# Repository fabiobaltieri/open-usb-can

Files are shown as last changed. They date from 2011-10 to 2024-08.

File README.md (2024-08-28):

Open-USB-CAN
============

This project is an USB to CANBus interface based on the ATMega32U2 and an
MCP2515 SPI CANBus controller.

The design features full electrical isolation for the CANBus interface and a
socketcan compliant Linux kernel driver.

> **Warning**
>
> This is not maintained or updated, please check out
> https://github.com/CANnectivity/ or
> https://github.com/candle-usb/candleLight_fw instead.

License
-------

This program is free software: you can redistribute it and/or modify
it under the terms of the GNU General Public License as published by
the Free Software Foundation, either version 3 of the License, or
(at your option) any later version.

Contents
--------

    COPYING        text version of the GPL
    README         this file
    hardware/      source directory for the hardware design files
    firmware/      source directory for the firmware source code
    kernel-module/ source directory for the kernel driver source code

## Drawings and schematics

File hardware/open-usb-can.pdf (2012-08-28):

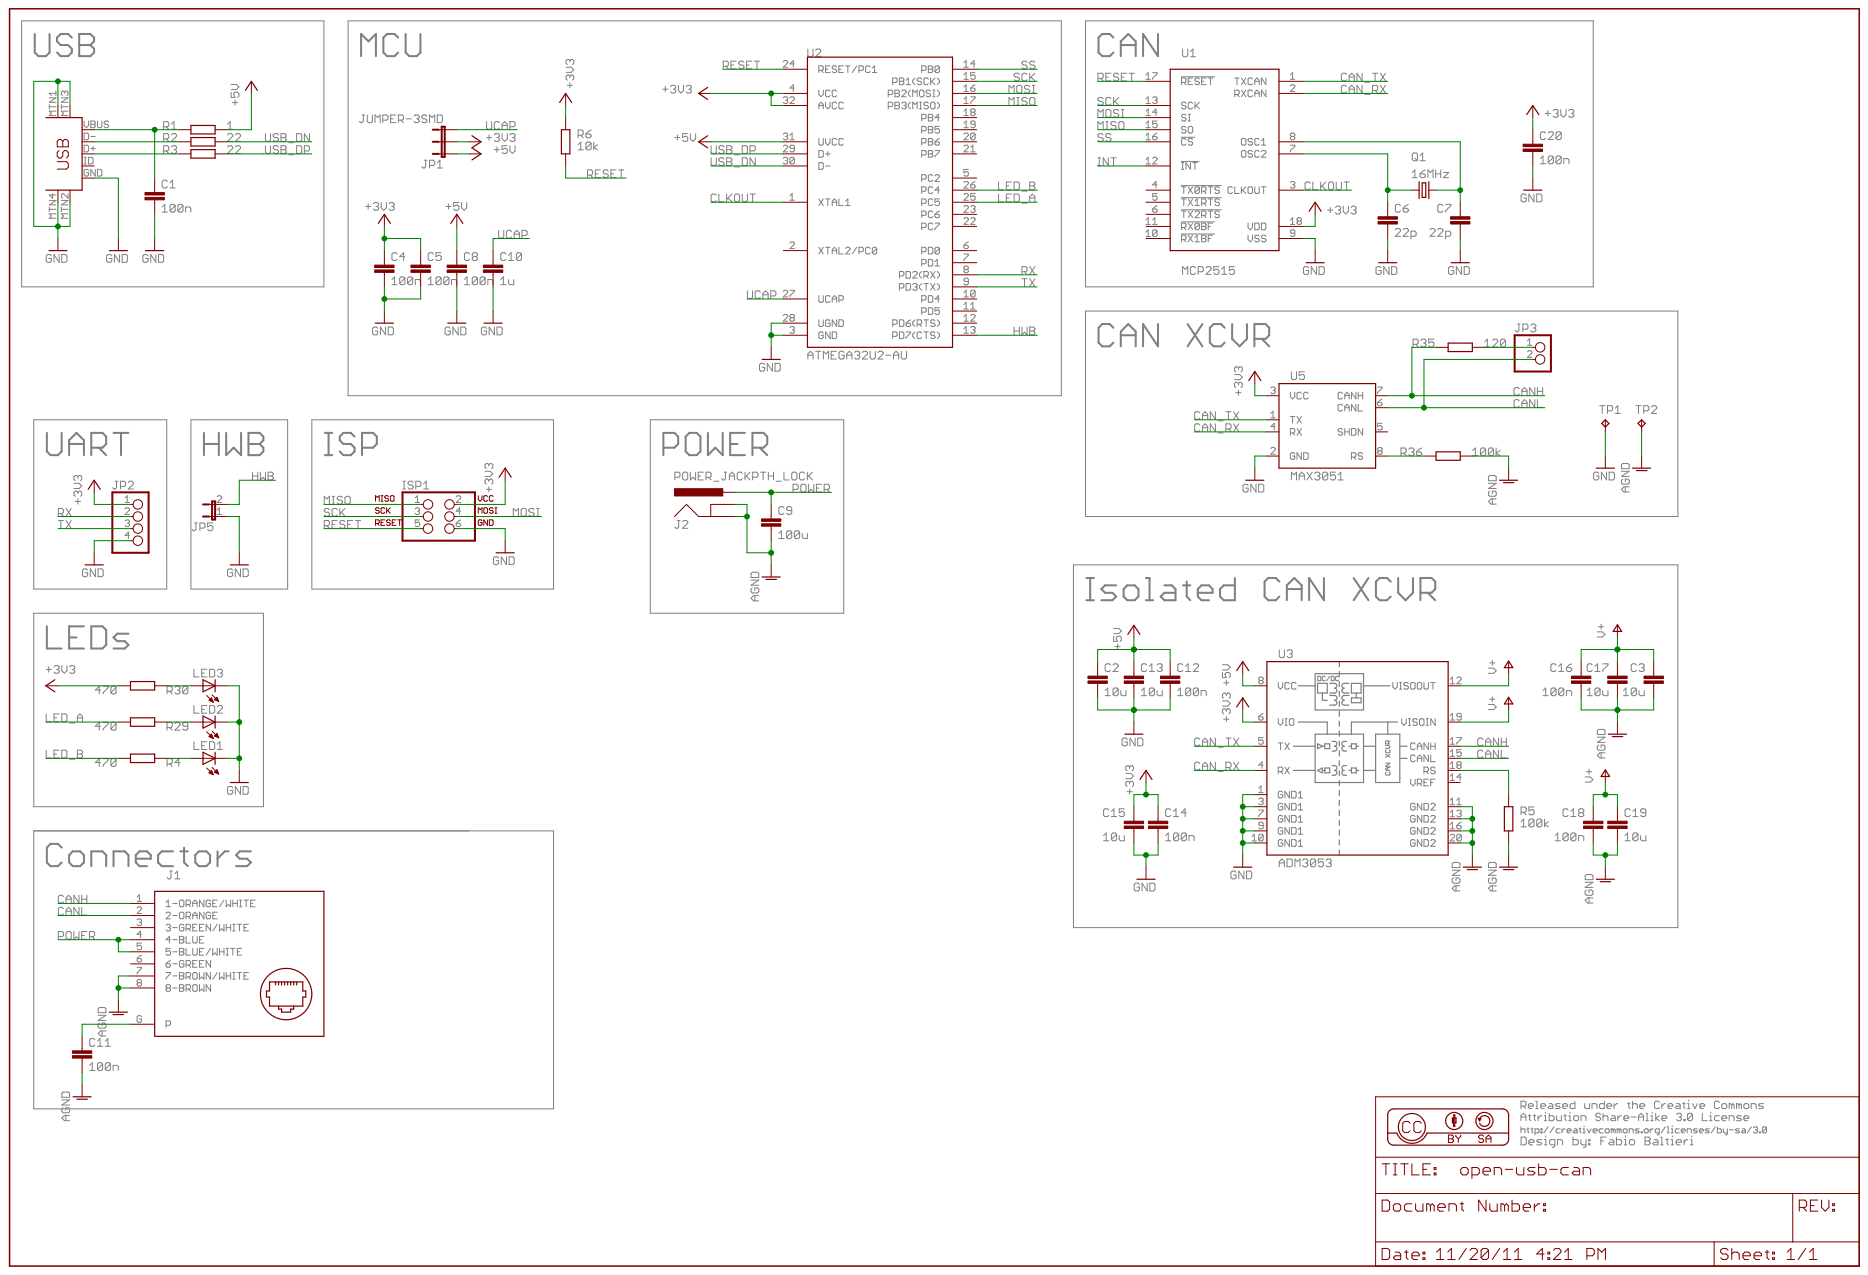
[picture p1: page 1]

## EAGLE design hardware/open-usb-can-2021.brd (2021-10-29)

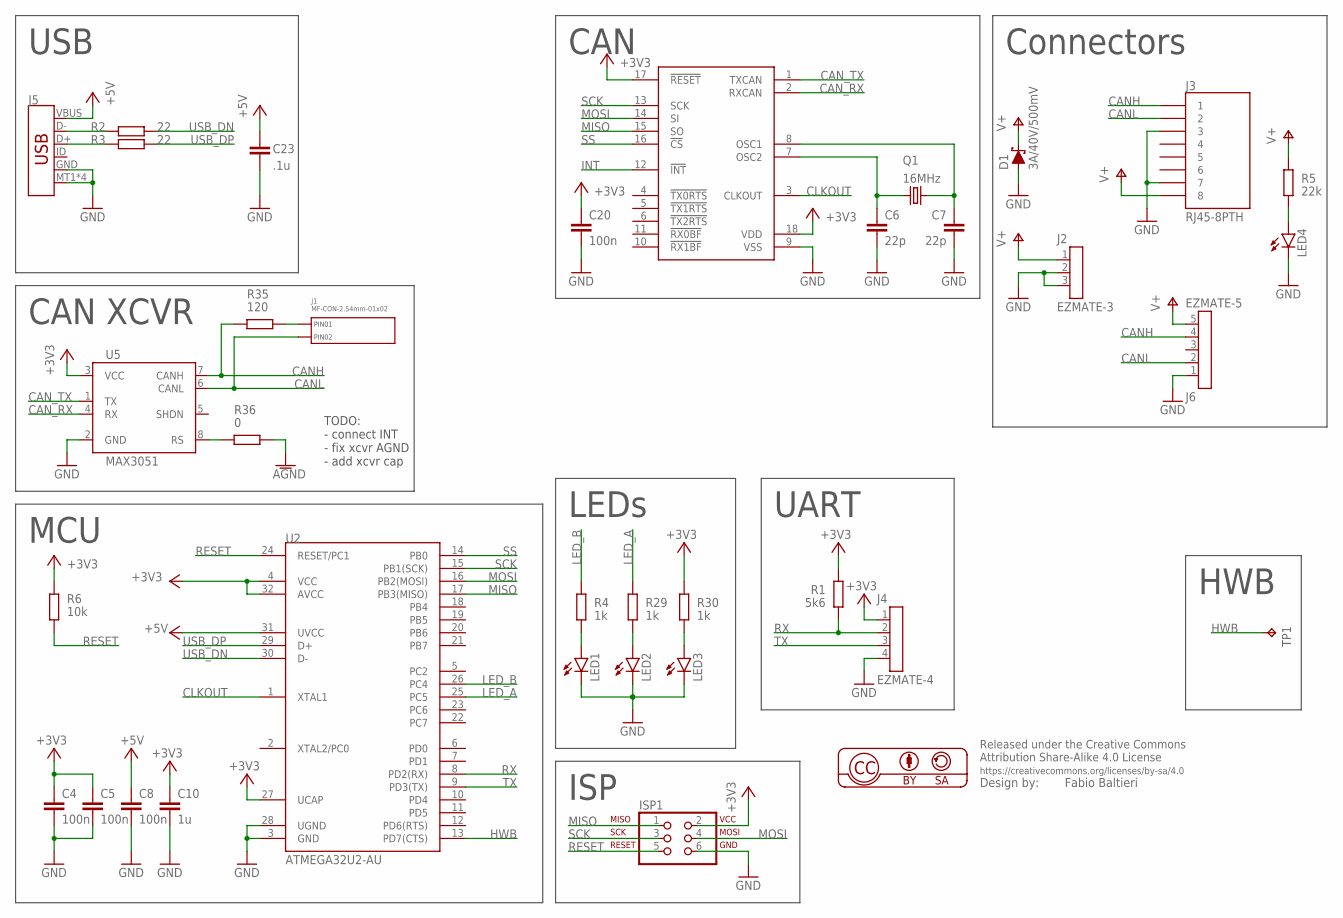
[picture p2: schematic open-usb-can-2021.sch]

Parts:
C4, C5, C8, C20: 100n; 0402
C6, C7: 22p; C0805
C10: 1u; 0603
C23: .1u; 0603
D1: 3A/40V/500mV; SMA-DIODE
ISP1: ISP-AVR910TP; 2X03_TP
J1: MF-CON-2.54mm-01x02; PTH_2.54MM_01X02
J2: EZMATE-3
J3: RJ45-8PTH; RJ45-8
J4: EZMATE-4
J5: USB_MICRO-B_SMT; USB-MICROB
J6: EZMATE-5
LED1, LED2, LED3, LED4: LEDCHIPLED_0603; CHIPLED_0603
Q1: 16MHz; HC49U-V
R1: 5k6; 0402
R2, R3: 22; 0603
R4, R29, R30: 1k; 0402
R5: 22k; 0603
R6: 10k; 0402
R35: 120; R0805
R36: 0; 0603
TP1: TPTP08R; TP08R
U1: MCP2515-I/P; SO-18DW
U2: ATMEGA32U2-AU; TQFP32-08
U5: MAX3051; SO08

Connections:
+3V3: C4.1, C5.1, C10.1, C20.1, ISP1.2, J4.1, R1.1, R6.1, R30.2, U1.17 (!RESET), U1.18 (VDD), U2.4 (VCC), U2.27 (UCAP), U2.32 (AVCC), U5.3 (VCC)
+5V: C8.1, C23.1, J5.VBUS, U2.31 (UVCC)
AGND: R36.2
CANH: J3.1, J6.4, R35.1, U5.7 (CANH)
CANL: J1.P$2 (PIN2), J3.2, J6.2, U5.6 (CANL)
CAN_RX: U1.2 (RXCAN), U5.4 (RX)
CAN_TX: U1.1 (TXCAN), U5.1 (TX)
CLKOUT: U1.3 (CLKOUT), U2.1 (XTAL1)
GND: C4.2, C5.2, C6.2, C7.2, C8.2, C10.2, C20.2, C23.2, D1.A, ISP1.6, J2.2, J2.3, J3.3, J3.7, J4.4, J5.GND, J5.MT1 (SHIELD), J5.MT2 (SHIELD), J5.P$1 (SHIELD), J5.P$2 (SHIELD), J6.1, LED1.C, LED2.C, LED3.C, LED4.C, U1.9 (VSS), U2.3 (GND), U2.28 (UGND), U5.2 (GND)
HWB: TP1.TP, U2.13 (PD7(CTS))
INT: U1.12 (!INT)
LED_A: R29.2, U2.25 (PC5)
LED_B: R4.2, U2.26 (PC4)
MISO: ISP1.1, U1.15 (SO), U2.17 (PB3(MISO))
MOSI: ISP1.4, U1.14 (SI), U2.16 (PB2(MOSI))
unnamed: J5.D-, R2.1
unnamed: J5.D+, R3.1
unnamed: C7.1, Q1.2, U1.8 (OSC1)
unnamed: C6.1, Q1.1, U1.7 (OSC2)
unnamed: LED4.A, R5.1
unnamed: LED1.A, R4.1
unnamed: LED2.A, R29.1
unnamed: LED3.A, R30.1
unnamed: R36.1, U5.8 (RS)
unnamed: J1.P$1 (PIN1), R35.2
RESET: ISP1.5, R6.2, U2.24 (RESET/PC1)
RX: J4.2, R1.2, U2.8 (PD2(RX))
SCK: ISP1.3, U1.13 (SCK), U2.15 (PB1(SCK))
SS: U1.16 (!CS), U2.14 (PB0)
TX: J4.3, U2.9 (PD3(TX))
USB_DN: R2.2, U2.30 (D-)
USB_DP: R3.2, U2.29 (D+)
V+: D1.C, J2.1, J3.8, J6.5, R5.2

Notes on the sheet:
UART
LEDs
ISP
MCU
USB
CAN
Connectors
CAN XCVR
HWB
TODO: - connect INT - fix xcvr AGND - add xcvr cap

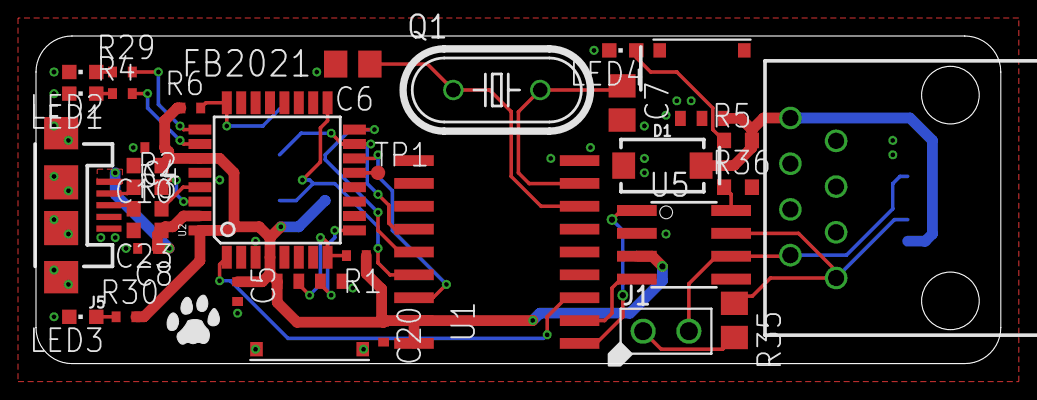
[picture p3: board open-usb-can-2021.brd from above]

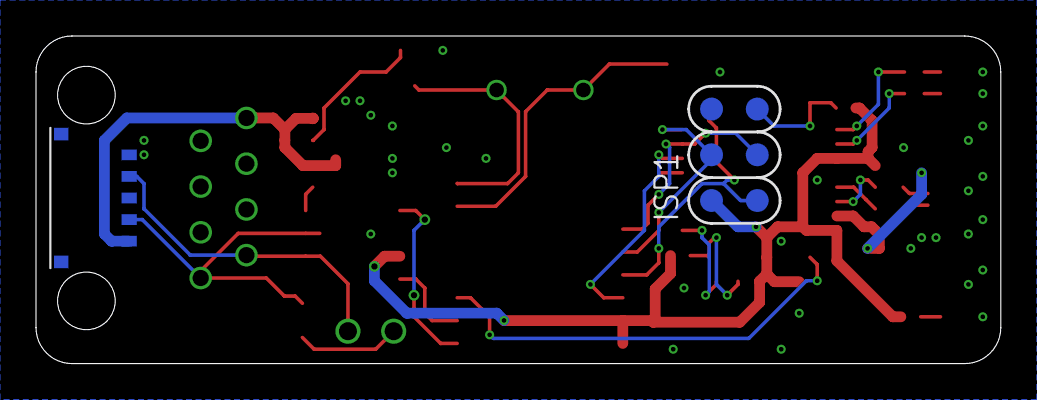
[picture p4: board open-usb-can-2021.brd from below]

Board: 4 copper layers, 53.6 x 18.2 mm, 36 parts (2 on the bottom side), 31 nets.

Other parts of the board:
U$1: CAT-L

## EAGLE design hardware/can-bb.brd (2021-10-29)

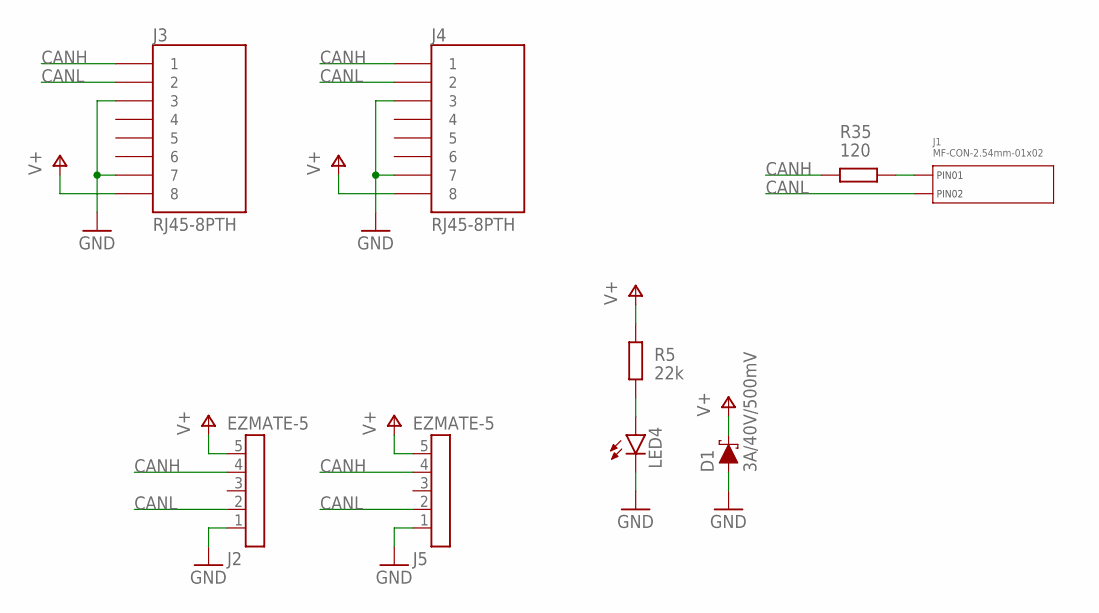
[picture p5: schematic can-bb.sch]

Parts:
D1: 3A/40V/500mV; SMA-DIODE
J1: MF-CON-2.54mm-01x02; PTH_2.54MM_01X02
J2, J5: EZMATE-5
J3, J4: RJ45-8PTH; RJ45-8
LED4: LEDCHIPLED_0603; CHIPLED_0603
R5: 22k; 0603
R35: 120; R0805

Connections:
CANH: J2.4, J3.1, J4.1, J5.4, R35.1
CANL: J1.P$2 (PIN2), J2.2, J3.2, J4.2, J5.2
GND: D1.A, J2.1, J3.3, J3.7, J4.3, J4.7, J5.1, LED4.C
unnamed: LED4.A, R5.1
unnamed: J1.P$1 (PIN1), R35.2
V+: D1.C, J2.5, J3.8, J4.8, J5.5, R5.2

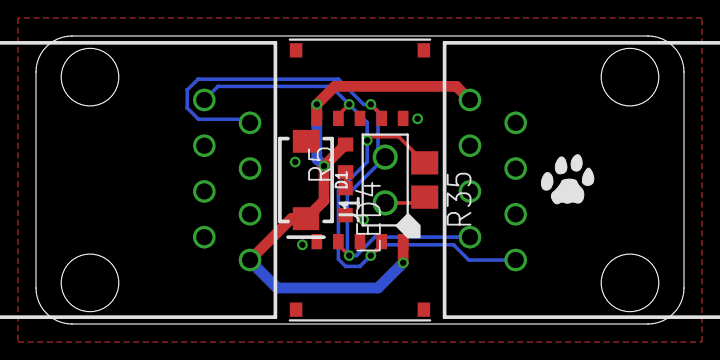
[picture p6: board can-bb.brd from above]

Board: 4 copper layers, 36.0 x 16.0 mm, 10 parts (0 on the bottom side), 6 nets.

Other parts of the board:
U$1: CAT-L

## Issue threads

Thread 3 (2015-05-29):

DFU mode using

iDoka, 2015-05-29:
Hi Fabio!
What approach I should using for burning FW into ATmega  in DFU-mode provided by proj?
As I know this chip already ships with pre-burned DFU-bootloader, and I would ask - what difference with code in "bootloader" folder?
Could I use with your bootloader vendor util like Atmel FLIP USB DFU?
Or maybe standard linux util lika dfu-util?
Thanks

fabiobaltieri, 2015-06-11:
Hi, the pre-burned dfu-bootloader can be used with FLIP, but I found it quite inconvenient to use since you have to move a jumper and power cycle the device. The bootloader I used always runs at startup and load the normal firmware after some seconds, allowing to reflash the main firmware with a soft-reset, without having to touch the board. Obviously the main firmware should run with both, so in the end you could just use the standard bootloader if it suits your needs.

Closed 2015-06-11.

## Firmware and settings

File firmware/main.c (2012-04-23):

/*
 * Copyright 2011 Fabio Baltieri <fabio.baltieri@gmail.com>
 *
 * Based on the original ben-wpan code written by
 *   Werner Almesberger, Copyright 2008-2011
 *
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
 */

#include <stdint.h>
#include <stdio.h>
#include <string.h>
#include <avr/io.h>
#include <avr/sleep.h>
#include <avr/interrupt.h>
#include <util/delay.h>

#include "defines.h"

#include "usb.h"
#include "board.h"
#include "descr.h"
#include "ep0.h"
#include "spi.h"
#include "can.h"
#include "buffer.h"
#include "mcp2515.h"
#include "blink.h"

void hello(void)
{
	uint8_t i;

	_delay_ms(100);

	for (i = 0; i < 5; i++) {
		led_a_on();
		led_b_on();

		_delay_ms(50);
		
		led_a_off();
		led_b_off();
		
		_delay_ms(50);
	}
}

int main(void)
{
	board_init();
	led_init();
	spi_init();
	blink_init();

	_delay_ms(10);

#if (F_CPU == 16000000UL)
	mcp2515_init(0);
#elif (F_CPU == 8000000UL)
	mcp2515_init(1);
#else
#error unsupported F_CPU value
#endif

	buffer_reset();

	usb_init();
	ep0_init();

	user_get_descriptor = strings_get_descr;

	/* move interrupt vectors to 0 */
	MCUCR = 1 << IVCE;
	MCUCR = 0;

	sei();

	hello();

	while (1) {
		cli();
		mcp2515_update_status();
		sei();
		buffer_tx_process();
		buffer_rx_process();

		//sleep_mode();
	}
}

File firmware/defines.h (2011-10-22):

/* buttons */
#define BUTTON_PORT PORTD
#define BUTTON_DDR  DDRD
#define BUTTON_PIN  PIND
#define BUTTON_HWB PC7

#define condition_init() { BUTTON_PORT |= _BV(BUTTON_HWB); }
#define button_read() (BUTTON_PIN & _BV(BUTTON_HWB))

/* leds */
#define LED_A_PORT PORTC
#define LED_A_DDR  DDRC
#define LED_A PC5
#define LED_B_PORT PORTC
#define LED_B_DDR DDRC
#define LED_B PC4

#define led_init() { LED_A_DDR |= _BV(LED_A); LED_B_DDR |= _BV(LED_B); }

#define led_a_on()     LED_A_PORT |=  _BV(LED_A)
#define led_a_off()    LED_A_PORT &= ~_BV(LED_A)
#define led_a_toggle() LED_A_PORT ^=  _BV(LED_A)
#define led_b_on()     LED_B_PORT |=  _BV(LED_B)
#define led_b_off()    LED_B_PORT &= ~_BV(LED_B)
#define led_b_toggle() LED_B_PORT ^=  _BV(LED_B)

/* CAN SPI */
#define SPI_DDR  DDRB
#define SPI_PORT PORTB
#define SPI_SS   PB0
#define SPI_SCK  PB1
#define SPI_MOSI PB2
#define SPI_MISO PB3

#define can_cs_h() (SPI_PORT |=  _BV(SPI_SS))
#define can_cs_l() (SPI_PORT &= ~_BV(SPI_SS))

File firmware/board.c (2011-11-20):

/*
 * Copyright 2011 Fabio Baltieri <fabio.baltieri@gmail.com>
 *
 * Based on the original ben-wpan code written by
 *   Werner Almesberger, Copyright 2011
 *
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
 */

#include <stdint.h>
#include <avr/io.h>
#include <avr/interrupt.h>
#include <avr/boot.h>
#include <util/delay.h>

#include "defines.h"

#include "usb.h"
#include "board.h"

void panic(void)
{
	cli();
	while (1) {
		led_a_on();
		led_b_on();
		_delay_ms(100);
		led_a_off();
		led_b_off();
		_delay_ms(100);
	}
}

void reset_cpu(void)
{
	WDTCSR = 1 << WDE;
}

int gpio(uint8_t port, uint8_t data, uint8_t dir, uint8_t mask, uint8_t *res)
{
	EIMSK = 0; /* recover INT_RF to ATUSB_GPIO_CLEANUP or an MCU reset */

	switch (port) {
	case 1:
		DDRB = (DDRB & ~mask) | dir;
		PORTB = (PORTB & ~mask) | data;
		break;
	case 2:
		DDRC = (DDRC & ~mask) | dir;
		PORTC = (PORTC & ~mask) | data;
		break;
	case 3:
		DDRD = (DDRD & ~mask) | dir;
		PORTD = (PORTD & ~mask) | data;
		break;
	default:
		return 0;
	}

	switch (port) {
	case 1:
		res[0] = PINB;
		res[1] = PORTB;
		res[2] = DDRB;
		break;
	case 2:
		res[0] = PINC;
		res[1] = PORTC;
		res[2] = DDRC;
		break;
	case 3:
		res[0] = PIND;
		res[1] = PORTD;
		res[2] = DDRD;
		break;
	}

	return 1;
}

void board_init(void)
{
	/* Disable the watchdog timer */

	MCUSR = 0;		/* Remove override */
	WDTCSR |= 1 << WDCE;	/* Enable change */
	WDTCSR = 1 << WDCE;	/* Disable watchdog while still enabling change */

	/* We start with a 1 MHz/8 clock. Disable the prescaler. */

	CLKPR = 1 << CLKPCE;
	CLKPR = 0;
}

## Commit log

2011-10-15 hardware: add hardware files
    [open-can-usb.brd, open-can-usb.sch]
2011-10-15 kernel-module: initial import of ems driver
2011-10-16 move NUM_EPS define out of board.h file
2011-10-16 board: minor cleanups
2011-10-16 main: move led_init in a separate function
2011-10-16 add canbus structures
2011-10-16 hardware: rename open-can-usb to open-usb-can
    [open-usb-can.brd, open-usb-can.sch]
2011-10-16 kernel-module: support multiple can packets per usb frame
2011-10-22 defines.h: fix pin mapping for open-usb-can board
    [defines.h, main.c]
2011-10-22 spi, mcp2515: add original drivers
2011-10-22 mcp2515: correct intendation, add txempty function
    [mcp2515.c]
2011-10-22 reworked free slots notification logic
2011-10-23 spi: start with chip select high
2011-10-23 main: add delay before first spi command
2011-10-25 buffer: add barriers around mcp/spi functions
2011-10-25 firmware: add led blink support
2011-10-26 kernel-module: add tx and rx debug printks
2011-10-26 ep0: reset buffers also on stop
    [ep0.c]
2011-11-02 handle /2 fixed clock divisor in firmware instead of kernel
    [mcp2515.c]
2011-11-12 mcp2515: reworked status flags logic
    [mcp2515.c]
2011-11-12 firmware: add 16MHz F_CPU option (for 5V boards)
2011-11-12 firmware: implement can error handling
    [mcp2515.c]
2011-11-12 Revert "handle /2 fixed clock divisor in firmware instead of kernel"
    This reverts commit 69abf564cfaf4b9aebedb0c5fbea37409a8667a1 as it was
    causing problems with canbus at maximum frequency.
    [mcp2515.c]
2011-11-20 hardware: add CC BY-SA license
    [open-usb-can.brd, open-usb-can.sch]
2012-04-23 firmware: fix indentation style
    [main.c, mcp2515.c, spi.c]
2012-04-23 firmware: change declared consumption to 100mA
2012-08-28 hw: add pdf schematics
2012-09-07 hw: clean up, update to eagle 6
    [open-usb-can.brd, open-usb-can.sch]
2012-09-16 fw: Makefile: add device ID to dfu-util
2012-11-13 hw: add rev2 rc0
    [open-usb-can-rev2.brd, open-usb-can-rev2.sch]
2021-10-12 hw: add 2021 board and can-bb
    [can-bb.brd, can-bb.sch, open-usb-can-2021.brd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]
2021-10-12 hw: drop rev2, never built
    [open-usb-can-rev2.brd, open-usb-can-rev2.sch]
2021-10-29 hw: 2021: add few notes
    [can-bb.brd, can-bb.sch, open-usb-can-2021.brd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]
2021-10-29 hw: 2021: fix a couple of schematic warnings
    [open-usb-can-2021.sch]

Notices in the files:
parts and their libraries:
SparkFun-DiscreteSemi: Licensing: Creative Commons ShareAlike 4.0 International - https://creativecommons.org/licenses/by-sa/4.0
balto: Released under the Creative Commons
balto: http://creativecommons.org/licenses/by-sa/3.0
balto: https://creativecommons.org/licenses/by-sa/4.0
